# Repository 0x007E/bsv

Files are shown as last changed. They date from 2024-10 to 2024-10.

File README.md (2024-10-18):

  

# `BSV` - (Bluetooth) Stereo Amplifier (Stereoverstärker)

The `BSV` project is based on a pcb with a transistor amplifier. It can be combined with a [Bluetooth audio module](https://eu.robotshop.com/de/products/bluetooth-50-audio-receiver-board) or with an audio jack only.

| Experience | Level |
|:---|:-----:|
| Soldering | ?% |
| Mechanical  | ?% |

# Downloads

| Type | File | Description |
|:---:|:---:|:---|
| Lochmaster | [lm4](https://github.com/0x007E/bsv/raw/refs/heads/main/BSV.LM4) | Stripe grid circuit board | 
| Schematic | [pdf](https://github.com/0x007E/bsv/releases/latest/download/schematic.pdf) / [cadlab](https://cadlab.io/project/28570/main/files) | Schematic files |
| Board | [pdf](https://github.com/0x007E/bsv/releases/latest/download/pcb.pdf) / [cadlab](https://cadlab.io/project/28570/main/files) | Board file |
| Drill | [pdf](https://github.com/0x007E/bsv/releases/latest/download/drill.pdf) | Drill file |
| Gerber | [zip](https://github.com/0x007E/bsv/releases/latest/download/kicad.zip) / [tar](https://github.com/0x007E/bsv/releases/latest/download/kicad.tar.gz) | Gerber/Drill files |
| Housing, PCB | [zip](https://github.com/0x007E/bsv/releases/latest/download/freecad.zip) / [tar](https://github.com/0x007E/bsv/releases/latest/download/freecad.tar.gz) | Housing and PCB (STEP) files |

# Hardware

There are two parts of the hardware. The pcb and the housing of the `BSV`. The pcb is created with `KiCAD` and the housing with `FreeCAD`. All files are built with `github actions` so that they are ready for a production environment. The housing is printed with a 3D-printer (`Dremel 3D40`).

## PCB

The circuit board is populated on one side (Top). The best way for soldering is within a standard soldering system.

### Top Layer

Top Layer

### Bottom Layer

Bottom Layer

## Mechanical

The housing has a tolerance of `0.2mm` on each side of the case. So the pcb should fit perfectly in the housing. The tolerance can be modified with `FreeCAD` in the `Parameter` Spreadsheet.

### Assembled

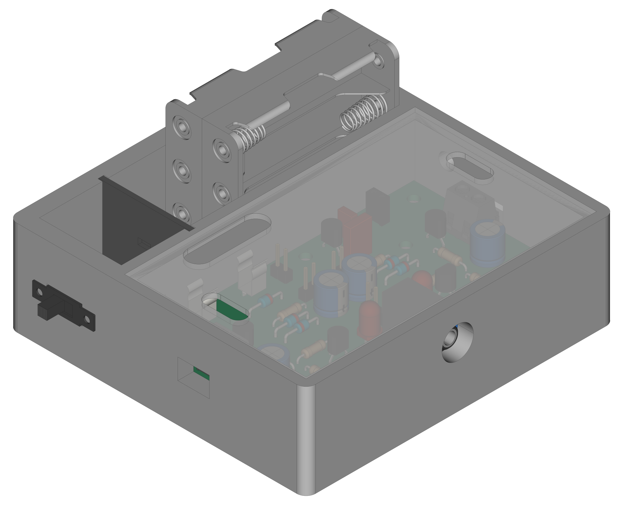
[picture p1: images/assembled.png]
Assembled


#### Exploded

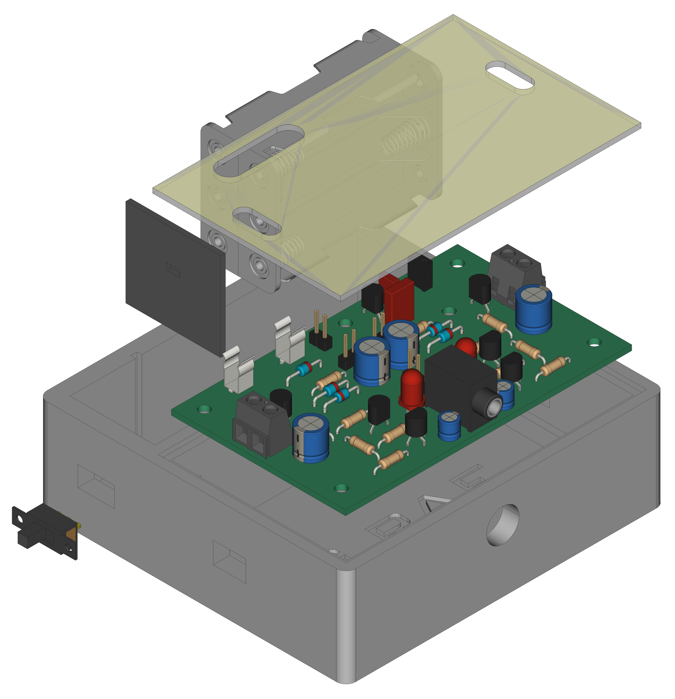
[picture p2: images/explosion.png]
Exploded


# Additional Information

| Type | Link | Description |
|:---:|:---:|:---|
| BC547 | [pdf](https://www.sparkfun.com/datasheets/Components/BC546.pdf) | NPN 
| BC327 | [pdf](https://www.onsemi.com/pdf/datasheet/bc327-d.pdf) | NPN 
| BC337 | [pdf](https://www.onsemi.cn/download/data-sheet/pdf/bc337-fsc-d.pdf) | PNP Transistor |

---

R. GAECHTER

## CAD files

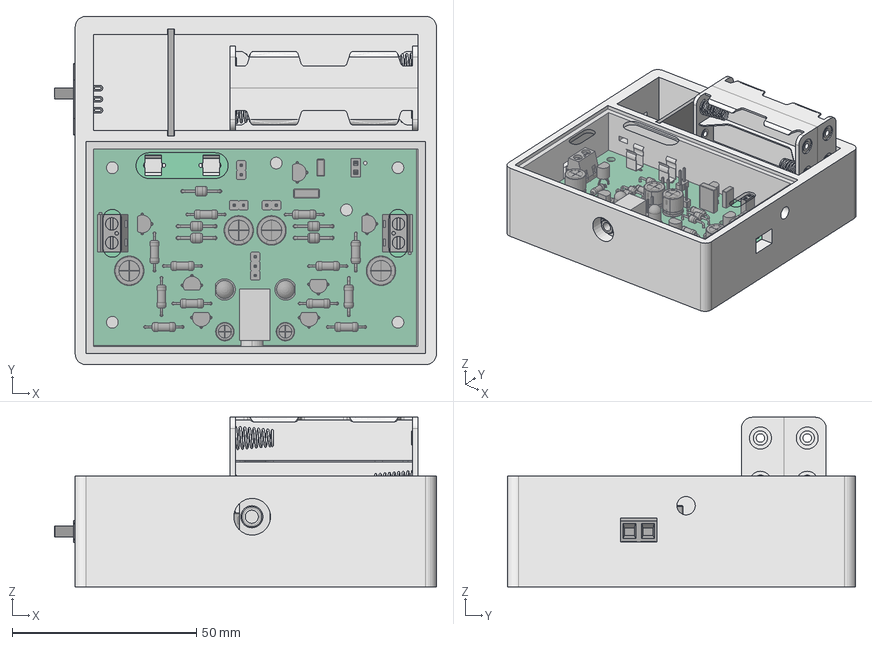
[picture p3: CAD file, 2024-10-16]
mechanical/housing.FCStd
103.6 x 94.5 x 46.0 mm
AcrylGlass
Separator
Switch
AAABlock
Pcb_1212
C4_CP_Radial_D80mm_P350mm_d8b62ba5375d
D6_D_T-1_P10.16mm_Horizontal_a208ecc29479
Q1_TO-92_Wide_242d9e4cc8b0
Q5_TO-92_Wide_89f1906d8e1f
D4_D_T-1_P10.16mm_Horizontal_8f5d68d4b9e9
J1_PinHeader_1x02_P254mm_Vertical_c40b434f67f6
Q6_TO-92_Wide_bc099332c6eb
C8_CP_Radial_D50mm_P200mm_853c0f8d8395
R7_R_Axial_DIN0207_L63mm_D25mm_P1016mm_Horizontal_89878cefc412
R9_R_Axial_DIN0207_L63mm_D25mm_P1016mm_Horizontal_fc6b94f905b1
J2_PinHeader_1x02_P254mm_Vertical_6b25811ab3e6
D2_LED_D5.0mm_d49e8d53d187
R2_R_Axial_DIN0207_L63mm_D25mm_P1016mm_Horizontal_5b398d8dbcca
C2_C_Rect_L46mm_W20mm_P250mm_MKS02_FKP02_917bdbac9085
C6_CP_Radial_D80mm_P350mm_684a26d2843f
Q4_TO-92_Wide_c5d5ff68a0c5
R8_R_Axial_DIN0207_L63mm_D25mm_P1016mm_Horizontal_1a2f3be1fe7b
R1_R_Axial_DIN0207_L63mm_D25mm_P1016mm_Horizontal_dc7424a02398
J3_PinHeader_1x02_P254mm_Vertical_34f4cf3e928b
D5_D_T-1_P10.16mm_Horizontal_000fe2ce875e
C7_CP_Radial_D50mm_P200mm_98af75f3c0ca
R10_R_Axial_DIN0207_L63mm_D25mm_P1016mm_Horizontal_ed84b4bcfb72
C3_CP_Radial_D80mm_P350mm_02dd2bbed7e8
J6_CUI_DEVICES_SJ1-3533NG_b46143e41cbf
D7_D_T-1_P10.16mm_Horizontal_7a857d3545cb
J5_PinHeader_1x03_P254mm_Vertical_28913cdcc784
U1_TO-92_Wide_491cda092b51
C5_CP_Radial_D80mm_P350mm_ab27f32c6bd0
LITTELFUSE_SERIES100_HOLDER_5X20MM
LITTELFUSE_SERIES100_HOLDER_5X20MM001
R5_R_Axial_DIN0207_L63mm_D25mm_P1016mm_Horizontal_e5da547dec65
LS1_C-282837-2_ccde75b77f8f
Q2_TO-92_Wide_be1599dfc824
D3_LED_D5.0mm_5d9a287f6ed2
R6_R_Axial_DIN0207_L63mm_D25mm_P1016mm_Horizontal_b06efe21b968
R12_R_Axial_DIN0207_L63mm_D25mm_P1016mm_Horizontal_cd16ab514bfc
R4_R_Axial_DIN0207_L63mm_D25mm_P1016mm_Horizontal_c702a263ce04
Q3_TO-92_Wide_90818151824d
LS2_C-282837-2_84b20681e291
R11_R_Axial_DIN0207_L63mm_D25mm_P1016mm_Horizontal_0336b8db8599
D1_D_T-1_P10.16mm_Horizontal_6ddf53cd3184
C1_C_Rect_L70mm_W25mm_P500mm_512169ed1952
J4_PinSocket_2x01_P254mm_Vertical_3e6bd14835b0
R3_R_Axial_DIN0207_L63mm_D25mm_P1016mm_Horizontal_22b4b9d273f5

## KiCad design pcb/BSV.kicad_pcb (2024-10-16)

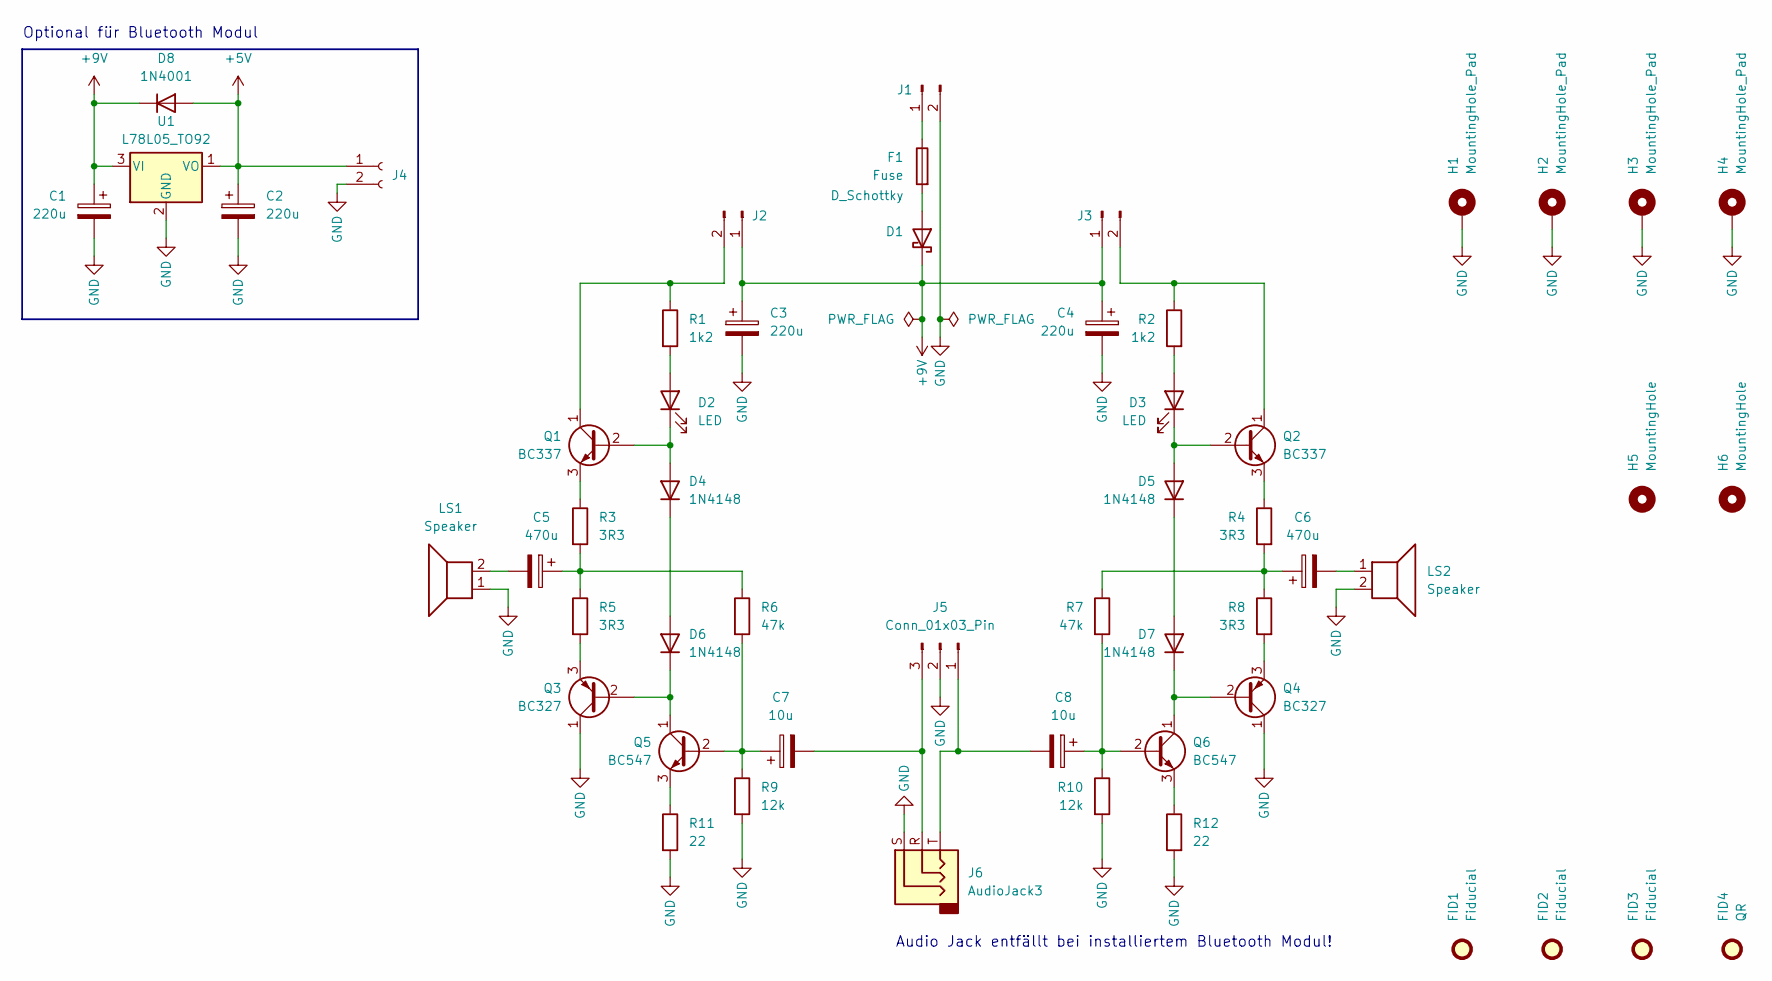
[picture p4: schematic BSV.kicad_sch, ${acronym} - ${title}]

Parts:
C1, C2: 220u; C_Radial_D6.3mm_H5.0mm_P2.50mm
C3, C4: 220u; CP_Radial_D8.0mm_P3.50mm
C5, C6: 470u; CP_Radial_D8.0mm_P3.50mm
C7, C8: 10u; CP_Radial_D5.0mm_P2.00mm
D1: D_Schottky; D_T-1_P10.16mm_Horizontal
D2, D3: LED; LED_D5.0mm
D4, D5, D6, D7: 1N4148; D_T-1_P10.16mm_Horizontal
D8: 1N4001; D_DO-41_SOD81_P10.16mm_Horizontal
F1: Fuse; Fuseholder_Clip-5x20mm_Littelfuse_111_Inline_P20.00x5.00mm_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
FID1: Fiducial; ESD-Logo_6.6x6mm_SilkScreen
FID2: Fiducial; OSHW-Logo2_7.3x6mm_SilkScreen
FID3: Fiducial; WEEE-Logo_4.2x6mm_SilkScreen
FID4: QR; QR_0x007e
H1, H2, H3, H4: MountingHole_Pad; MountingHole_3.2mm_M3_DIN965_Pad
H5, H6: MountingHole; MountingHole_3.2mm_M3
J1, J2, J3: Conn_01x02_Pin; PinHeader_1x02_P2.54mm_Vertical
J4: Conn_01x02_Socket; PinSocket_2x01_P2.54mm_Vertical
J5: Conn_01x03_Pin; PinHeader_1x03_P2.54mm_Vertical
J6: AudioJack3; Jack_3.5mm_CUI_SJ1-3533NG_Horizontal
LS1, LS2: Speaker; TerminalBlock_bornier-2_P5.08mm
Q1, Q2: BC337; TO-92_Wide
Q3, Q4: BC327; TO-92_Wide
Q5, Q6: BC547; TO-92_Wide
R1, R2: 1k2; R_Axial_DIN0207_L6.3mm_D2.5mm_P10.16mm_Horizontal
R3, R4, R5, R8: 3R3; R_Axial_DIN0207_L6.3mm_D2.5mm_P10.16mm_Horizontal
R6, R7: 47k; R_Axial_DIN0207_L6.3mm_D2.5mm_P10.16mm_Horizontal
R9, R10: 12k; R_Axial_DIN0207_L6.3mm_D2.5mm_P10.16mm_Horizontal
R11, R12: 22; R_Axial_DIN0207_L6.3mm_D2.5mm_P10.16mm_Horizontal
U1: L78L05_TO92; TO-92L_Wide

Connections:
+5V: C2.1, D8.2 (A), J4.1, U1.1 (VO)
+9V: C1.1, C3.1, C4.1, D1.1 (K), D8.1 (K), J2.1, J3.1, U1.3 (VI)
GND: C1.2, C2.2, C3.2, C4.2, H1.1, H2.1, H3.1, H4.1, J1.2, J4.2, J5.2, J6.S, LS1.1, LS2.2, Q3.1 (C), Q4.1 (C), R9.2, R10.2, R11.2, R12.2, U1.2 (GND)
unnamed: C5.1, R3.2, R5.1, R6.1
unnamed: C5.2, LS1.2
unnamed: C6.1, R4.2, R7.1, R8.1
unnamed: C6.2, LS2.1
unnamed: D1.2 (A), F1.2
unnamed: D2.2 (A), R1.2
unnamed: D2.1 (K), D4.2 (A), Q1.2 (B)
unnamed: D3.2 (A), R2.2
unnamed: D3.1 (K), D5.2 (A), Q2.2 (B)
unnamed: D4.1 (K), D6.2 (A)
unnamed: D5.1 (K), D7.2 (A)
unnamed: D6.1 (K), Q3.2 (B), Q5.1 (C)
unnamed: D7.1 (K), Q4.2 (B), Q6.1 (C)
unnamed: F1.1, J1.1
unnamed: J2.2, Q1.1 (C), R1.1
unnamed: J3.2, Q2.1 (C), R2.1
unnamed: C8.2, J5.1, J6.T
unnamed: C7.2, J5.3, J6.R
unnamed: Q1.3 (E), R3.1
unnamed: Q2.3 (E), R4.1
unnamed: Q3.3 (E), R5.2
unnamed: Q4.3 (E), R8.2
unnamed: C7.1, Q5.2 (B), R6.2, R9.1
unnamed: Q5.3 (E), R11.1
unnamed: C8.1, Q6.2 (B), R7.2, R10.1
unnamed: Q6.3 (E), R12.1

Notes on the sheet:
Audio Jack entfällt bei installiertem Bluetooth Modul!
Optional für Bluetooth Modul

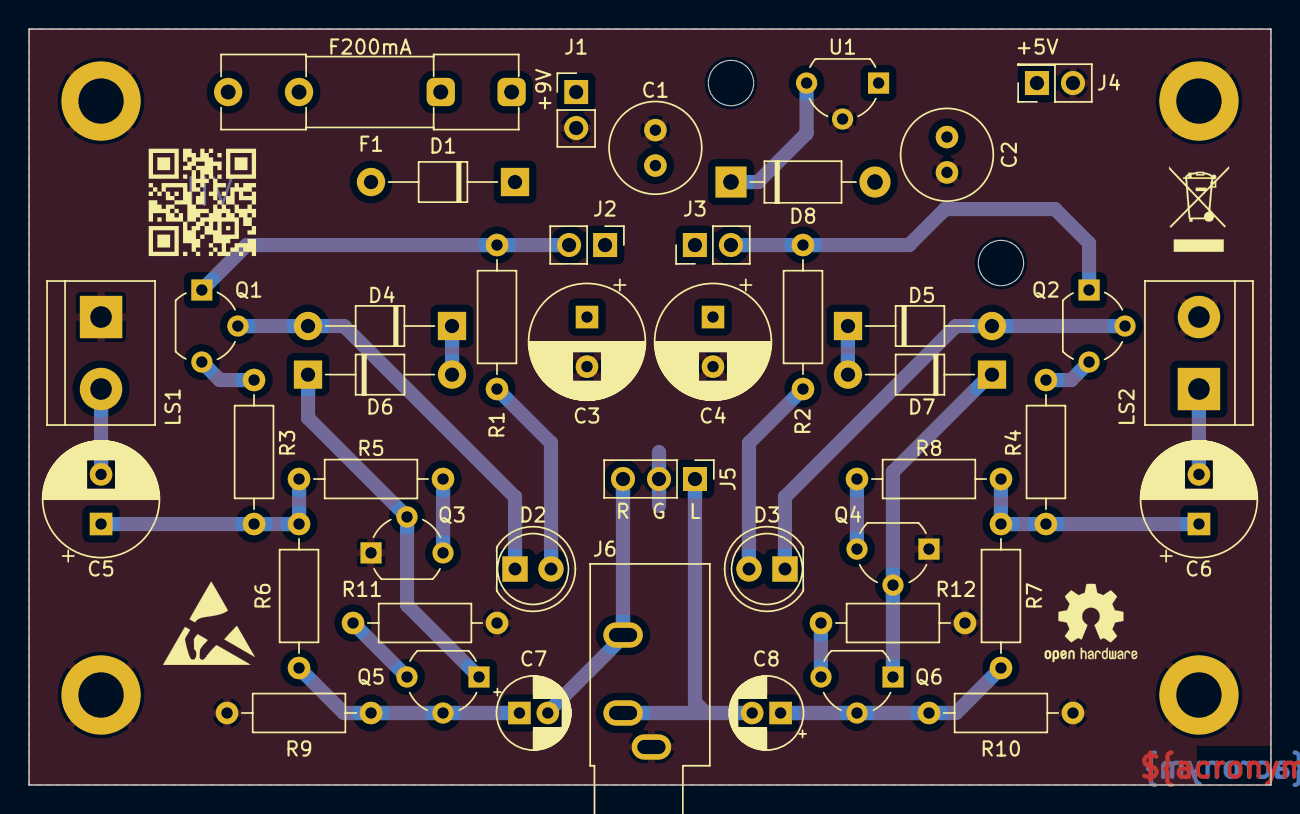
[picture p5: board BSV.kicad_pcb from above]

Board: 2 copper layers, 87.6 x 53.3 mm, 54 parts (0 on the bottom side), 29 nets.

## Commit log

2024-10-16 Fix e/drc filter
2024-10-16 Adapt PCB variables
    [BSV.kicad_pcb]

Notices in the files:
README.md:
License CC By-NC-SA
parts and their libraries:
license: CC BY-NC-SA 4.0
